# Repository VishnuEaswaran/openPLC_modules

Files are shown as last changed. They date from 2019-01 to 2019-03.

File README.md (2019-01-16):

# OpenPLC Modules

Addon modules for OpenPLC experiments.
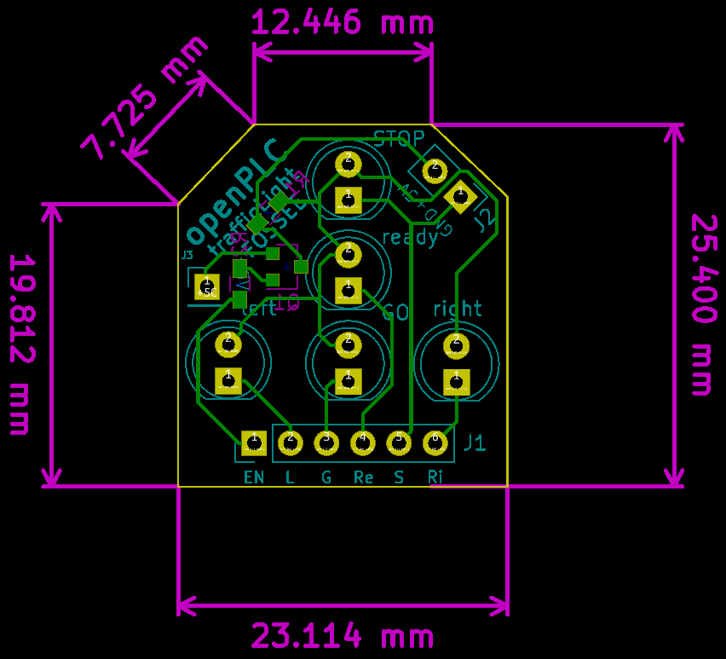
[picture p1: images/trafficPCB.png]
traffic
- Traffic light - represent a 3 way traffic light 
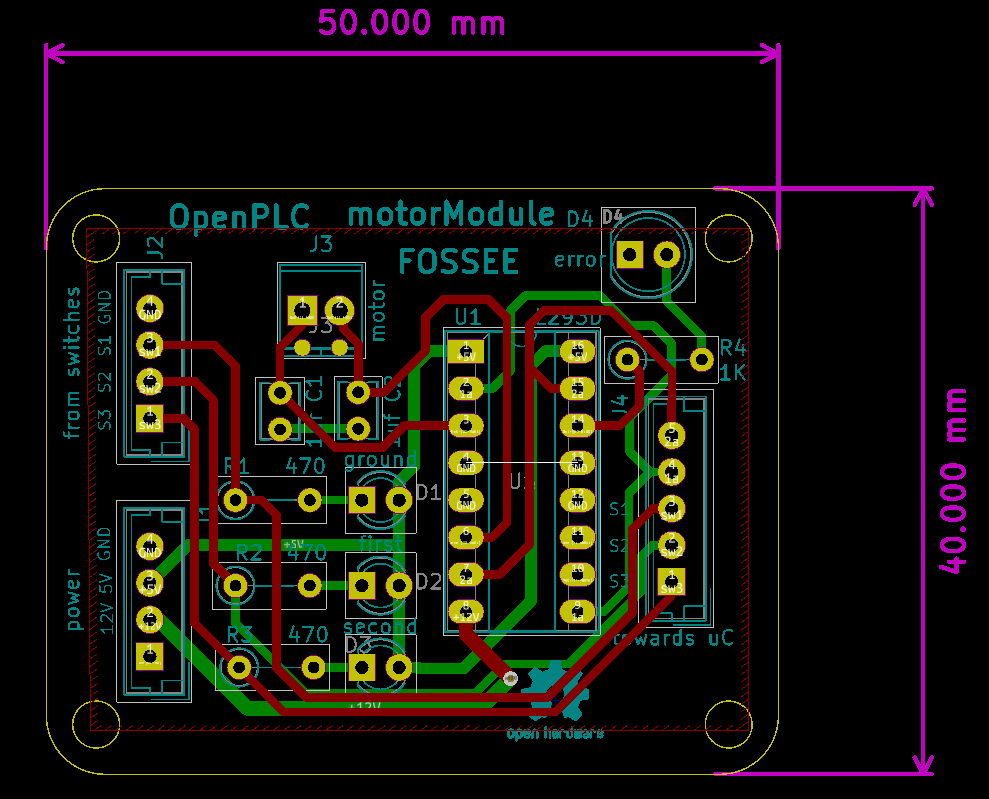
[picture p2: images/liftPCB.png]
- Motor driver for lift - circuit required for driving the motor, receiving and passing on the limit-switch state and as an indicator showing the given logic 
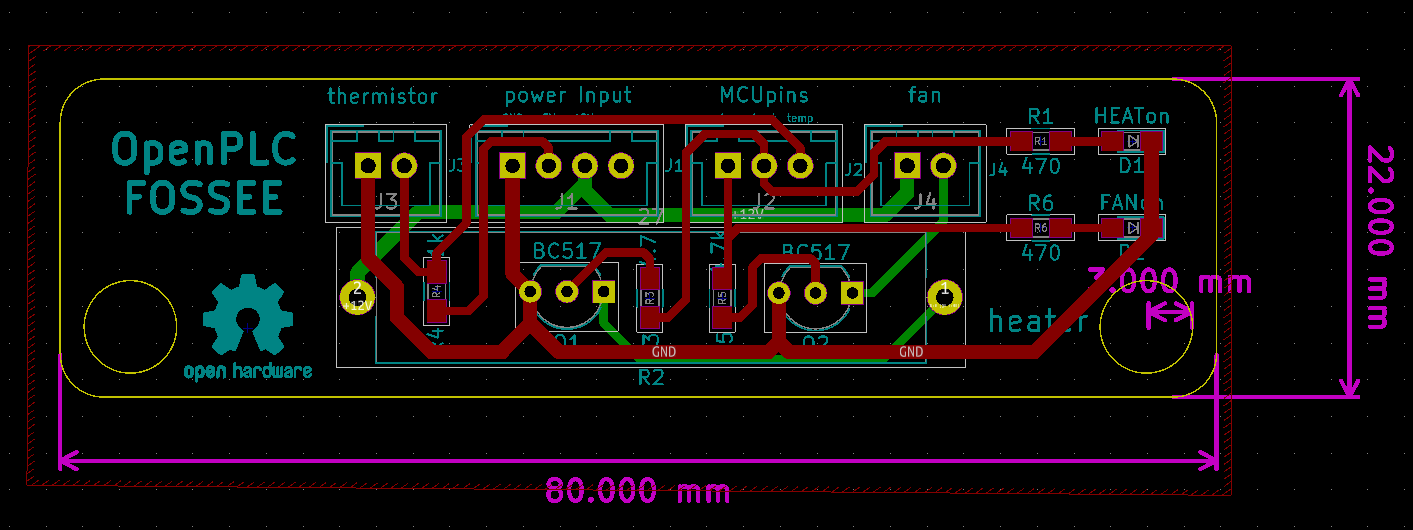
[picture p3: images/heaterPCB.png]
- Heater/temperature control - elements to drive the roister, which also doubles as the heating element, the cooling fan and collecting and passing on thermistor values 
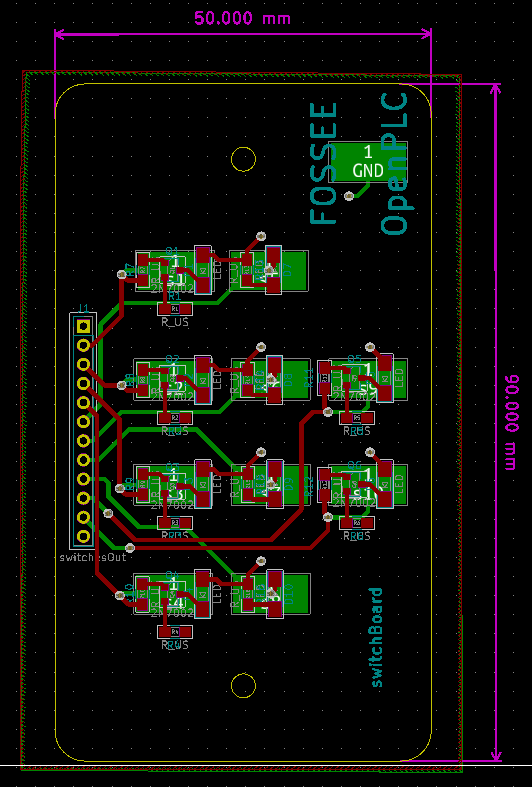
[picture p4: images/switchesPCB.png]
- Switches - an array of a combination of NO, NC and latch switches with indicator LEDs

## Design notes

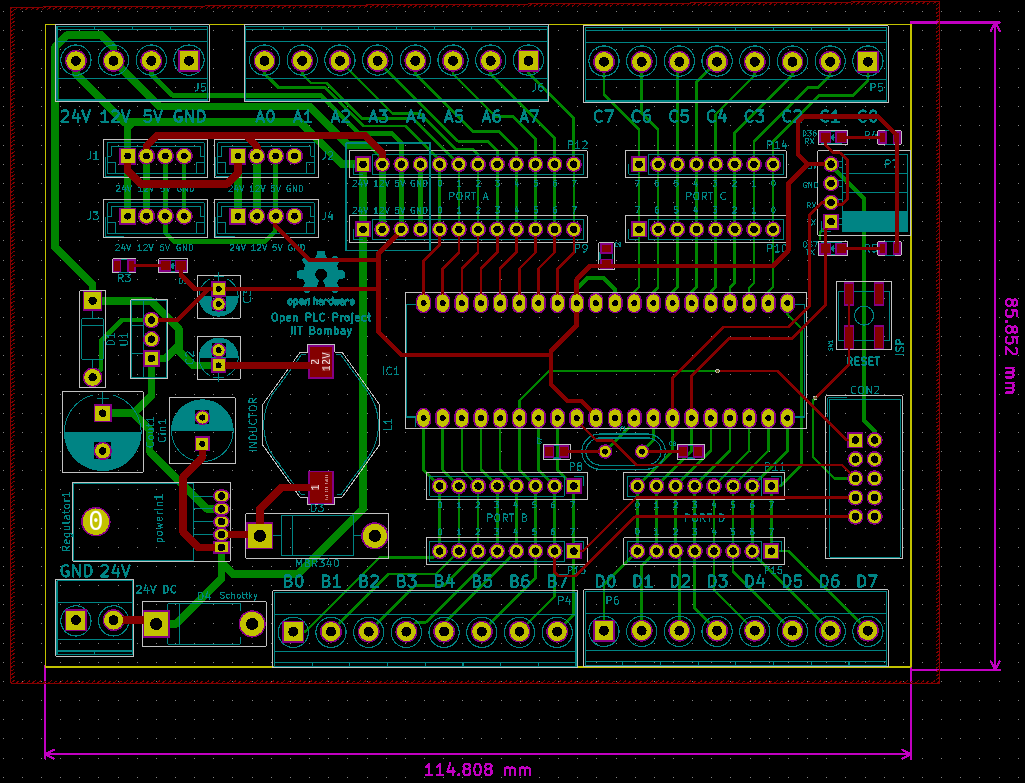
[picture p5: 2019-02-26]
images/v1.png

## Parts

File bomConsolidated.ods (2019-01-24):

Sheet: v1
Date: | Tue 22 Jan 2019 12:48:19 PM IST
Tool: | Eeschema 5.0.1
Component Count: | 41
Individual Components:
Item | Qty | Reference(s) | Value | LibPart | Footprint | Datasheet
 |  | C2 | 100uF | OpenPLC_V2-rescue:CP | Capacitors_THT:CP_Radial_D5.0mm_P2.00mm
 |  | C3 | 10uF | OpenPLC_V2-rescue:CP | Capacitors_THT:CP_Radial_D5.0mm_P2.00mm
 |  | C7 | 22pF | OpenPLC_V2-rescue:CP1 | Capacitors_SMD:C_0805
 |  | C8 | 22pF | OpenPLC_V2-rescue:CP1 | Capacitors_SMD:C_0805
 |  | C9 | 100nF | OpenPLC_V2-rescue:C_Small | Capacitors_SMD:C_0805
 |  | CON2 | AVR-ISP-10 | OpenPLC_V2-rescue:AVR-ISP-10 | IDC:IDC-Header_2x05_Pitch2.54mm_Straight
 |  | Cin1 | 100uf | Device:CP | Capacitors_THT:CP_Radial_D8.0mm_P3.50mm
 |  | Cout1 | 1000uf | Device:CP | Capacitors_THT:CP_Radial_D10.0mm_P5.00mm
 |  | D1 | D | OpenPLC_V2-rescue:D | Diodes_THT:D_DO-41_SOD81_P10.16mm_Horizontal
 |  | D2 | LED | OpenPLC_Kicad_Single_Strip_Unordered-rescue:LED-RESCUE-OpenPLC_Kicad_Single_Strip_Unordered | LEDs:LED_0805
 |  | D3 | MBR340 | Diode:MBR340 | Diodes_THT:D_DO-201AD_P15.24mm_Horizontal | http://www.onsemi.com/pub_link/Collateral/MBR340-D.PDF
 |  | D4 | D_Schottky | OpenPLC_V2-rescue:D_Schottky-Device | Diodes_THT:D_DO-201AD_P12.70mm_Horizontal | ~
 |  | D36 | RX | OpenPLC_Kicad_Single_Strip_Unordered-rescue:LED-RESCUE-OpenPLC_Kicad_Single_Strip_Unordered | LEDs:LED_0805
 |  | D37 | TX | OpenPLC_Kicad_Single_Strip_Unordered-rescue:LED-RESCUE-OpenPLC_Kicad_Single_Strip_Unordered | LEDs:LED_0805
 |  | IC1 | ATMEGA16-P | OpenPLC_Modular-rescue:ATMEGA16-P-RESCUE-OpenPLC_Modular | Housings_DIP:DIP-40_W15.24mm_LongPads
 |  | J1 | Conn_01x04 | OpenPLC_V2-rescue:Conn_01x04 | Connectors_JST:JST_EH_B04B-EH-A_04x2.50mm_Straight
 |  | J2 | Conn_01x04 | OpenPLC_V2-rescue:Conn_01x04 | Connectors_JST:JST_EH_B04B-EH-A_04x2.50mm_Straight
 |  | J3 | Conn_01x04 | OpenPLC_V2-rescue:Conn_01x04 | Connectors_JST:JST_EH_B04B-EH-A_04x2.50mm_Straight
 |  | J4 | Conn_01x04 | OpenPLC_V2-rescue:Conn_01x04 | Connectors_JST:JST_EH_B04B-EH-A_04x2.50mm_Straight
 |  | L1 | INDUCTOR | OpenPLC_V2-rescue:INDUCTOR | Inductors_SMD:L_Fastron_PISR_Handsoldering
 |  | P3 | PortA | OpenPLC_V2-rescue:Conn_01x12 | TerminalBlocks_Phoenix:TerminalBlock_Phoenix_MKDS1.5-12pol
 |  | P4 | PortB | OpenPLC_V2-rescue:Conn_01x08 | TerminalBlocks_Phoenix:TerminalBlock_Phoenix_MKDS1.5-8pol
 |  | P5 | PortC | OpenPLC_V2-rescue:Conn_01x08 | TerminalBlocks_Phoenix:TerminalBlock_Phoenix_MKDS1.5-8pol
 |  | P6 | PortD | OpenPLC_V2-rescue:Conn_01x08 | TerminalBlocks_Phoenix:TerminalBlock_Phoenix_MKDS1.5-8pol
 |  | P7 | Max232 | OpenPLC_V2-rescue:Conn_01x04 | Socket_Strips:Socket_Strip_Angled_1x04_Pitch2.54mm
 |  | P8 | PortB_B | OpenPLC_V2-rescue:Conn_01x08 | Socket_Strips:Socket_Strip_Straight_1x08_Pitch2.54mm
 |  | P9 | PortA_B | OpenPLC_V2-rescue:Conn_01x12 | Socket_Strips:Socket_Strip_Straight_1x12_Pitch2.54mm
 |  | P10 | PortC_B | OpenPLC_V2-rescue:Conn_01x08 | Socket_Strips:Socket_Strip_Straight_1x08_Pitch2.54mm
 |  | P11 | PortD_B | OpenPLC_V2-rescue:Conn_01x08 | Socket_Strips:Socket_Strip_Straight_1x08_Pitch2.54mm
 |  | P12 | PortA_M | OpenPLC_V2-rescue:Conn_01x12 | Pin_Headers:Pin_Header_Straight_1x12_Pitch2.54mm
 |  | P13 | PortB_M | OpenPLC_V2-rescue:Conn_01x08 | Pin_Headers:Pin_Header_Straight_1x08_Pitch2.54mm
 |  | P14 | PortC_M | OpenPLC_V2-rescue:Conn_01x08 | Pin_Headers:Pin_Header_Straight_1x08_Pitch2.54mm
 |  | P15 | PortD_M | OpenPLC_V2-rescue:Conn_01x08 | Pin_Headers:Pin_Header_Straight_1x08_Pitch2.54mm
 |  | R3 | 470E | OpenPLC_V2-rescue:R | Resistors_SMD:R_0805
 |  | R4 | 1K | OpenPLC_V2-rescue:R_Small | Resistors_SMD:R_0805
 |  | R5 | 1K | OpenPLC_V2-rescue:R_Small | Resistors_SMD:R_0805
 |  | Regulator1 | 24 to 12 | Regulator_Switching:LM2576HVT-12 | TO_SOT_Packages_THT:TO-220-5_Horizontal | http://www.ti.com/lit/ds/symlink/lm2576.pdf
 |  | SW1 | SW_PUSH | OpenPLC_V2-rescue:SW_PUSH | Buttons_Switches_SMD:SW_SPST_B3SL-1002P
 |  | U1 | 7805 | OpenPLC_Kicad_Single_Strip_Unordered-rescue:7805-RESCUE-OpenPLC_Kicad_Single_Strip_Unordered | TO_SOT_Packages_THT:TO-220-3_Vertical
 |  | Y1 | 16Mhz | OpenPLC_V2-rescue:Crystal | Crystals:Crystal_HC49-U_Vertical
 |  | powerIn1 | 24V | OpenPLC_V2-rescue:Screw_Terminal_01x02-Connector | TerminalBlocks_Phoenix:TerminalBlock_Phoenix_MKDS1.5-2pol | ~
Collated Components:
Item | Qty | Reference(s) | Value | LibPart | Footprint | Datasheet
1 | 1 | C2 | 100uF | OpenPLC_V2-rescue:CP | Capacitors_THT:CP_Radial_D5.0mm_P2.00mm
2 | 1 | C3 | 10uF | OpenPLC_V2-rescue:CP | Capacitors_THT:CP_Radial_D5.0mm_P2.00mm
3 | 2 | C7, C8 | 22pF | OpenPLC_V2-rescue:CP1 | Capacitors_SMD:C_0805
4 | 1 | C9 | 100nF | OpenPLC_V2-rescue:C_Small | Capacitors_SMD:C_0805
5 | 1 | CON2 | AVR-ISP-10 | OpenPLC_V2-rescue:AVR-ISP-10 | IDC:IDC-Header_2x05_Pitch2.54mm_Straight
6 | 1 | Cin1 | 100uf | Device:CP | Capacitors_THT:CP_Radial_D8.0mm_P3.50mm
7 | 1 | Cout1 | 1000uf | Device:CP | Capacitors_THT:CP_Radial_D10.0mm_P5.00mm
8 | 1 | D1 | D | OpenPLC_V2-rescue:D | Diodes_THT:D_DO-41_SOD81_P10.16mm_Horizontal
9 | 1 | D2 | LED | OpenPLC_Kicad_Single_Strip_Unordered-rescue:LED-RESCUE-OpenPLC_Kicad_Single_Strip_Unordered | LEDs:LED_0805
10 | 1 | D3 | MBR340 | Diode:MBR340 | Diodes_THT:D_DO-201AD_P15.24mm_Horizontal | http://www.onsemi.com/pub_link/Collateral/MBR340-D.PDF
11 | 1 | D4 | D_Schottky | OpenPLC_V2-rescue:D_Schottky-Device | Diodes_THT:D_DO-201AD_P12.70mm_Horizontal | ~
12 | 1 | D36 | RX | OpenPLC_Kicad_Single_Strip_Unordered-rescue:LED-RESCUE-OpenPLC_Kicad_Single_Strip_Unordered | LEDs:LED_0805
13 | 1 | D37 | TX | OpenPLC_Kicad_Single_Strip_Unordered-rescue:LED-RESCUE-OpenPLC_Kicad_Single_Strip_Unordered | LEDs:LED_0805
14 | 1 | IC1 | ATMEGA16-P | OpenPLC_Modular-rescue:ATMEGA16-P-RESCUE-OpenPLC_Modular | Housings_DIP:DIP-40_W15.24mm_LongPads
15 | 4 | J1, J2, J3, J4 | Conn_01x04 | OpenPLC_V2-rescue:Conn_01x04 | Connectors_JST:JST_EH_B04B-EH-A_04x2.50mm_Straight
16 | 1 | L1 | INDUCTOR | OpenPLC_V2-rescue:INDUCTOR | Inductors_SMD:L_Fastron_PISR_Handsoldering
17 | 1 | P3 | PortA | OpenPLC_V2-rescue:Conn_01x12 | TerminalBlocks_Phoenix:TerminalBlock_Phoenix_MKDS1.5-12pol
18 | 1 | P4 | PortB | OpenPLC_V2-rescue:Conn_01x08 | TerminalBlocks_Phoenix:TerminalBlock_Phoenix_MKDS1.5-8pol
19 | 1 | P5 | PortC | OpenPLC_V2-rescue:Conn_01x08 | TerminalBlocks_Phoenix:TerminalBlock_Phoenix_MKDS1.5-8pol
20 | 1 | P6 | PortD | OpenPLC_V2-rescue:Conn_01x08 | TerminalBlocks_Phoenix:TerminalBlock_Phoenix_MKDS1.5-8pol
21 | 1 | P7 | Max232 | OpenPLC_V2-rescue:Conn_01x04 | Socket_Strips:Socket_Strip_Angled_1x04_Pitch2.54mm
22 | 1 | P8 | PortB_B | OpenPLC_V2-rescue:Conn_01x08 | Socket_Strips:Socket_Strip_Straight_1x08_Pitch2.54mm
23 | 1 | P9 | PortA_B | OpenPLC_V2-rescue:Conn_01x12 | Socket_Strips:Socket_Strip_Straight_1x12_Pitch2.54mm
24 | 1 | P10 | PortC_B | OpenPLC_V2-rescue:Conn_01x08 | Socket_Strips:Socket_Strip_Straight_1x08_Pitch2.54mm
25 | 1 | P11 | PortD_B | OpenPLC_V2-rescue:Conn_01x08 | Socket_Strips:Socket_Strip_Straight_1x08_Pitch2.54mm
26 | 1 | P12 | PortA_M | OpenPLC_V2-rescue:Conn_01x12 | Pin_Headers:Pin_Header_Straight_1x12_Pitch2.54mm
27 | 1 | P13 | PortB_M | OpenPLC_V2-rescue:Conn_01x08 | Pin_Headers:Pin_Header_Straight_1x08_Pitch2.54mm
28 | 1 | P14 | PortC_M | OpenPLC_V2-rescue:Conn_01x08 | Pin_Headers:Pin_Header_Straight_1x08_Pitch2.54mm
29 | 1 | P15 | PortD_M | OpenPLC_V2-rescue:Conn_01x08 | Pin_Headers:Pin_Header_Straight_1x08_Pitch2.54mm
30 | 1 | R3 | 470E | OpenPLC_V2-rescue:R | Resistors_SMD:R_0805
31 | 2 | R4, R5 | 1K | OpenPLC_V2-rescue:R_Small | Resistors_SMD:R_0805
32 | 1 | Regulator1 | 24 to 12 | Regulator_Switching:LM2576HVT-12 | TO_SOT_Packages_THT:TO-220-5_Horizontal | http://www.ti.com/lit/ds/symlink/lm2576.pdf
33 | 1 | SW1 | SW_PUSH | OpenPLC_V2-rescue:SW_PUSH | Buttons_Switches_SMD:SW_SPST_B3SL-1002P
34 | 1 | U1 | 7805 | OpenPLC_Kicad_Single_Strip_Unordered-rescue:7805-RESCUE-OpenPLC_Kicad_Single_Strip_Unordered | TO_SOT_Packages_THT:TO-220-3_Vertical
35 | 1 | Y1 | 16Mhz | OpenPLC_V2-rescue:Crystal | Crystals:Crystal_HC49-U_Vertical
36 | 1 | powerIn1 | 24V | OpenPLC_V2-rescue:Screw_Terminal_01x02-Connector | TerminalBlocks_Phoenix:TerminalBlock_Phoenix_MKDS1.5-2pol | ~
Extras
Item | Qty | Part
1 | 1 | USB-ASP Programmer
2 | 1 | Programmer cable

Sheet: traffic
Date: | Tue 22 Jan 2019 05:36:43 PM IST
Tool: | Eeschema 5.0.1
Component Count: | 11
Individual Components:
Reference(s) | Value | LibPart | Footprint | Datasheet
D1 | left | Device:LED | LEDs:LED_D5.0mm | ~
D2 | GO | Device:LED | LEDs:LED_D5.0mm | ~
D3 | right | Device:LED | LEDs:LED_D5.0mm | ~
D4 | ready | Device:LED | LEDs:LED_D5.0mm | ~
D5 | STOP | Device:LED | LEDs:LED_D5.0mm | ~
J1 | Conn_01x06_Male | Connector:Conn_01x06_Male | Socket_Strips:Socket_Strip_Straight_1x06_Pitch2.54mm | ~
J2 | Conn_01x02_Male | Connector:Conn_01x02_Male | Socket_Strips:Socket_Strip_Straight_1x02_Pitch2.54mm | ~
J3 | Conn_01x01_Male | Connector:Conn_01x01_Male | Socket_Strips:Socket_Strip_Straight_1x01_Pitch2.54mm |  |  | ~
Q1 | MMBT3906 | Transistor_BJT:MMBT3906 | TO_SOT_Packages_SMD:SOT-23 | https://www.fairchildsemi.com/datasheets/2N/2N3906.pdf | Q1 | MMBT3906 | Transistor_BJT:MMBT3906 | TO_SOT_Packages_SMD:SOT-23 | https://www.fairchildsemi.com/datasheets/2N/2N3906.pdf | Q1 | MMBT3906 | Transistor_BJT:MMBT3906 | TO_SOT_Packages_SMD:SOT-23 | https://www.fairchildsemi.com/datasheets/2N/2N3906.pdf | Q1 | MMBT3906 | Transistor_BJT:MMBT3906 | TO_SOT_Packages_SMD:SOT-23 | https://www.fairchildsemi.com/datasheets/2N/2N3906.pdf | Q1 | MMBT3906 | Transistor_BJT:MMBT3906 | TO_SOT_Packages_SMD:SOT-23 | https://www.fairchildsemi.com/datasheets/2N/2N3906.pdf | Q1 | MMBT3906 | Transistor_BJT:MMBT3906 | TO_SOT_Packages_SMD:SOT-23 | https://www.fairchildsemi.com/datasheets/2N/2N3906.pdf | Q1 | MMBT3906 | Transistor_BJT:MMBT3906 | TO_SOT_Packages_SMD:SOT-23 | https://www.fairchildsemi.com/datasheets/2N/2N3906.pdf | Q1 | MMBT3906 | Transistor_BJT:MMBT3906 | TO_SOT_Packages_SMD:SOT-23 | https://www.fairchildsemi.com/datasheets/2N/2N3906.pdf | Q1 | MMBT3906 | Transistor_BJT:MMBT3906 | TO_SOT_Packages_SMD:SOT-23 | https://www.fairchildsemi.com/datasheets/2N/2N3906.pdf | Q1 | MMBT3906 | Transistor_BJT:MMBT3906 | TO_SOT_Packages_SMD:SOT-23 | https://www.fairchildsemi.com/datasheets/2N/2N3906.pdf | Q1 | MMBT3906 | Transistor_BJT:MMBT3906 | TO_SOT_Packages_SMD:SOT-23 | https://www.fairchildsemi.com/datasheets/2N/2N3906.pdf | Q1 | MMBT3906 | Transistor_BJT:MMBT3906 | TO_SOT_Packages_SMD:SOT-23 | https://www.fairchildsemi.com/datasheets/2N/2N3906.pdf
R1 | R | Device:R | Resistors_SMD:R_0603_HandSoldering | ~
R2 | R | Device:R | Resistors_SMD:R_0603_HandSoldering | ~
Collated Components:
Item | Qty | Reference(s) | Value | LibPart | Footprint | Datasheet
1 | 1 | D1 | left | Device:LED – green | LEDs:LED_D5.0mm | ~
2 | 1 | D2 | GO | Device:LED – green | LEDs:LED_D5.0mm | ~
3 | 1 | D3 | right | Device:LED – green | LEDs:LED_D5.0mm | ~
4 | 1 | D4 | ready | Device:LED – orange | LEDs:LED_D5.0mm | ~
5 | 1 | D5 | STOP | Device:LED – green | LEDs:LED_D5.0mm | ~
6 | 1 | J1 | Conn_01x06_Male | Connector:Conn_01x06_Male | Socket_Strips:Socket_Strip_Straight_1x06_Pitch2.54mm | ~
7 | 1 | J2 | Conn_01x02_Male | Connector:Conn_01x02_Male | Socket_Strips:Socket_Strip_Straight_1x02_Pitch2.54mm | ~
8 | 1 | J3 | Conn_01x01_Male | Connector:Conn_01x01_Male | Socket_Strips:Socket_Strip_Straight_1x01_Pitch2.54mm | ~
9 | 1 | Q1 | MMBT3906 | Transistor_BJT:MMBT3906 | TO_SOT_Packages_SMD:SOT-23 | https://www.fairchildsemi.com/datasheets/2N/2N3906.pdf
10 | 2 | R1, R2 | R | Device:R | Resistors_SMD:R_0603_HandSoldering | ~

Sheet: motor
Date: | Tue 22 Jan 2019 12:15:49 PM IST
Tool: | Eeschema 5.0.1
Component Count: | 15
Individual Components:
Reference(s) | Value | LibPart | Footprint | Datasheet
C1 | 1uf | Device:C | Capacitors_THT:C_Disc_D3.8mm_W2.6mm_P2.50mm | ~
C2 | 1uf | Device:C | Capacitors_THT:C_Disc_D3.8mm_W2.6mm_P2.50mm | ~
D1 | LED | Device:LED | LEDs:LED_D3.0mm | ~
D2 | LED | Device:LED | LEDs:LED_D3.0mm | ~
D3 | LED | Device:LED | LEDs:LED_D3.0mm | ~
D4 | error | Device:LED | LEDs:LED_D5.0mm | ~
J1 | power | Connector:Conn_01x04_Male | Connectors_JST:JST_EH_B04B-EH-A_04x2.50mm_Straight | ~
J2 | from switches | Connector:Conn_01x04_Male | Connectors_JST:JST_EH_B04B-EH-A_04x2.50mm_Straight | ~
J3 | motor | Connector:Screw_Terminal_01x02 | TerminalBlocks_Phoenix:TerminalBlock_Phoenix_MPT-2.54mm_2pol | ~
J4 | towards uC | Connector:Conn_01x05_Male | Connectors_JST:JST_EH_B05B-EH-A_05x2.50mm_Straight | ~
R1 | 470 | Device:R_US | Resistors_THT:R_Axial_DIN0207_L6.3mm_D2.5mm_P5.08mm_Vertical | ~
R2 | 470 | Device:R_US | Resistors_THT:R_Axial_DIN0207_L6.3mm_D2.5mm_P5.08mm_Vertical | ~
R3 | 470 | Device:R_US | Resistors_THT:R_Axial_DIN0207_L6.3mm_D2.5mm_P5.08mm_Vertical | ~
R4 | 1K | Device:R_US | Resistors_THT:R_Axial_DIN0207_L6.3mm_D2.5mm_P5.08mm_Vertical | ~
U1 | L293D | Driver_Motor:L293D | Housings_DIP:DIP-16_W7.62mm_Socket_LongPads | http://www.ti.com/lit/ds/symlink/l293.pdf
Collated Components:
Item | Qty | Reference(s) | Value | LibPart | Footprint | Datasheet
1 | 2 | C1, C2 | 1uf | Device:C | Capacitors_THT:C_Disc_D3.8mm_W2.6mm_P2.50mm | ~
2 | 3 | D1, D2, D3 | LED | Device:LED – green | LEDs:LED_D3.0mm | ~
3 | 1 | D4 | error | Device:LED – red | LEDs:LED_D5.0mm | ~
4 | 1 | J1 | power | Connector:Conn_01x04_Male | Connectors_JST:JST_EH_B04B-EH-A_04x2.50mm_Straight | ~
5 | 1 | J2 | from switches | Connector:Conn_01x04_Male | Connectors_JST:JST_EH_B04B-EH-A_04x2.50mm_Straight | ~
6 | 1 | J3 | motor | Connector:Screw_Terminal_01x02 | TerminalBlocks_Phoenix:TerminalBlock_Phoenix_MPT-2.54mm_2pol | ~
7 | 1 | J4 | towards uC | Connector:Conn_01x05_Male | Connectors_JST:JST_EH_B05B-EH-A_05x2.50mm_Straight | ~
8 | 3 | R1, R2, R3 | 470 | Device:R_US | Resistors_THT:R_Axial_DIN0207_L6.3mm_D2.5mm_P5.08mm_Vertical | ~
9 | 1 | R4 | 1K | Device:R_US | Resistors_THT:R_Axial_DIN0207_L6.3mm_D2.5mm_P5.08mm_Vertical | ~
10 | 1 | U1 | L293D | Driver_Motor:L293D | Housings_DIP:DIP-16_W7.62mm_Socket_LongPads | http://www.ti.com/lit/ds/symlink/l293.pdf

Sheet: heater
Date: | Tue 22 Jan 2019 12:19:13 PM IST
Tool: | Eeschema 5.0.1
Component Count: | 14
Date Issue | 2019-01-04
Individual Components:
Reference(s) | Value | LibPart | Footprint | Datasheet
D1 | LED | Device:LED | LEDs:LED_0805_HandSoldering | ~
D2 | LED | Device:LED | LEDs:LED_0805_HandSoldering | ~
J1 | power Input | Connector:Conn_01x04_Female | Connectors_JST:JST_XH_B04B-XH-A_04x2.50mm_Straight | ~
J2 | MCUpins | Connector:Conn_01x03_Male | Connectors_JST:JST_XH_B03B-XH-A_03x2.50mm_Straight | ~
J3 | thermistor | Connector:Conn_01x02_Male | Connectors_JST:JST_XH_B02B-XH-A_02x2.50mm_Straight | ~
J4 | fan | Connector:Conn_01x02_Male | Connectors_JST:JST_XH_B02B-XH-A_02x2.50mm_Straight | ~
Q1 | BC517 | Transistor_BJT:BC517 | TO_SOT_Packages_THT:TO-92_Inline_Wide | http://www.fairchildsemi.com/ds/BC/BC517.pdf
Q2 | BC517 | Transistor_BJT:BC517 | TO_SOT_Packages_THT:TO-92_Inline_Wide | http://www.fairchildsemi.com/ds/BC/BC517.pdf
R1 | 470 | Device:R_US | Resistors_SMD:R_0805_HandSoldering | ~
R2 | 27 | Device:R_US | Resistors_THT:R_Axial_Power_L38.0mm_W9.0mm_P40.64mm | ~
R3 | 4.7 | Device:R_US | Resistors_SMD:R_0805_HandSoldering | ~
R4 | 1k | Device:R_US | Resistors_SMD:R_0805_HandSoldering | ~
R5 | 4.7k | Device:R_US | Resistors_SMD:R_0805_HandSoldering | ~
R6 | 470 | Device:R_US | Resistors_SMD:R_0805_HandSoldering | ~
Collated Components:
Item | Qty | Reference(s) | Value | LibPart | Footprint | Datasheet
1 | 2 | D1, D2 | LED | Device:LED | LEDs:LED_0805_HandSoldering | ~
2 | 1 | J1 | power Input | Connector:Conn_01x04_Female | Connectors_JST:JST_XH_B04B-XH-A_04x2.50mm_Straight | ~
3 | 1 | J2 | MCUpins | Connector:Conn_01x03_Male | Connectors_JST:JST_XH_B03B-XH-A_03x2.50mm_Straight | ~
4 | 1 | J3 | thermistor | Connector:Conn_01x02_Male | Connectors_JST:JST_XH_B02B-XH-A_02x2.50mm_Straight | ~
5 | 1 | J4 | fan | Connector:Conn_01x02_Male | Connectors_JST:JST_XH_B02B-XH-A_02x2.50mm_Straight | ~
6 | 2 | Q1, Q2 | BC517 | Transistor_BJT:BC517 | TO_SOT_Packages_THT:TO-92_Inline_Wide | http://www.fairchildsemi.com/ds/BC/BC517.pdf
7 | 2 | R1, R6 | 470 | Device:R_US | Resistors_SMD:R_0805_HandSoldering | ~
8 | 1 | R2 | 27 | Device:R_US | Resistors_THT:R_Axial_Power_L38.0mm_W9.0mm_P40.64mm | ~
9 | 1 | R3 | 4.7 | Device:R_US | Resistors_SMD:R_0805_HandSoldering | ~
10 | 1 | R4 | 1k | Device:R_US | Resistors_SMD:R_0805_HandSoldering | ~
11 | 1 | R5 | 4.7k | Device:R_US | Resistors_SMD:R_0805_HandSoldering | ~

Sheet: switches
Date: | Tue 22 Jan 2019 11:39:28 AM IST
Tool: | Eeschema 5.0.1
Component Count: | 44
Individual Components:
Reference(s) | Value | LibPart | Footprint | Datasheet
D1 | LED | Device:LED | LEDs:LED_1206_HandSoldering | ~
D2 | LED | Device:LED | LEDs:LED_1206_HandSoldering | ~
D3 | LED | Device:LED | LEDs:LED_1206_HandSoldering | ~
D4 | LED | Device:LED | LEDs:LED_1206_HandSoldering | ~
D5 | LED | Device:LED | LEDs:LED_1206_HandSoldering | ~
D6 | LED | Device:LED | LEDs:LED_1206_HandSoldering | ~
D7 | LED | Device:LED | LEDs:LED_1206_HandSoldering | ~
D8 | LED | Device:LED | LEDs:LED_1206_HandSoldering | ~
D9 | LED | Device:LED | LEDs:LED_1206_HandSoldering | ~
D10 | LED | Device:LED | LEDs:LED_1206_HandSoldering | ~
J1 | switchesOut | Connector:Conn_01x12_Male | Socket_Strips:Socket_Strip_Straight_1x12_Pitch2.54mm | ~
J2 | Conn_01x01_Female | Connector:Conn_01x01_Female | Wire_Pads:SolderWirePad_single_SMD_5x10mm | ~
J3 | Conn_01x01_Female | Connector:Conn_01x01_Female | Wire_Pads:SolderWirePad_single_SMD_5x10mm | ~
J4 | Conn_01x01_Female | Connector:Conn_01x01_Female | Wire_Pads:SolderWirePad_single_SMD_5x10mm | ~
J5 | Conn_01x01_Female | Connector:Conn_01x01_Female | Wire_Pads:SolderWirePad_single_SMD_5x10mm | ~
J6 | Conn_01x01_Female | Connector:Conn_01x01_Female | Wire_Pads:SolderWirePad_single_SMD_5x10mm | ~
J7 | Conn_01x01_Female | Connector:Conn_01x01_Female | Wire_Pads:SolderWirePad_single_SMD_5x10mm | ~
J8 | Conn_01x01_Female | Connector:Conn_01x01_Female | Wire_Pads:SolderWirePad_single_SMD_5x10mm | ~
J9 | Conn_01x01_Female | Connector:Conn_01x01_Female | Wire_Pads:SolderWirePad_single_SMD_5x10mm | ~
J10 | Conn_01x01_Female | Connector:Conn_01x01_Female | Wire_Pads:SolderWirePad_single_SMD_5x10mm | ~
J11 | Conn_01x01_Female | Connector:Conn_01x01_Female | Wire_Pads:SolderWirePad_single_SMD_5x10mm | ~
J12 | Conn_01x01_Female | Connector:Conn_01x01_Female | Wire_Pads:SolderWirePad_single_SMD_5x10mm | ~
Q1 | 2N7002 | Transistor_FET:2N7002 | TO_SOT_Packages_SMD:SOT-23 | https://www.fairchildsemi.com/datasheets/2N/2N7002.pdf
Q2 | 2N7002 | Transistor_FET:2N7002 | TO_SOT_Packages_SMD:SOT-23 | https://www.fairchildsemi.com/datasheets/2N/2N7002.pdf
Q3 | 2N7002 | Transistor_FET:2N7002 | TO_SOT_Packages_SMD:SOT-23 | https://www.fairchildsemi.com/datasheets/2N/2N7002.pdf
Q4 | 2N7002 | Transistor_FET:2N7002 | TO_SOT_Packages_SMD:SOT-23 | https://www.fairchildsemi.com/datasheets/2N/2N7002.pdf
Q5 | 2N7002 | Transistor_FET:2N7002 | TO_SOT_Packages_SMD:SOT-23 | https://www.fairchildsemi.com/datasheets/2N/2N7002.pdf
Q6 | 2N7002 | Transistor_FET:2N7002 | TO_SOT_Packages_SMD:SOT-23 | https://www.fairchildsemi.com/datasheets/2N/2N7002.pdf
R1 | R_US | Device:R_US | Resistors_SMD:R_0805_HandSoldering | ~
R2 | R_US | Device:R_US | Resistors_SMD:R_0805_HandSoldering | ~
R3 | R_US | Device:R_US | Resistors_SMD:R_0805_HandSoldering | ~
R4 | R_US | Device:R_US | Resistors_SMD:R_0805_HandSoldering | ~
R5 | R_US | Device:R_US | Resistors_SMD:R_0805_HandSoldering | ~
R6 | R_US | Device:R_US | Resistors_SMD:R_0805_HandSoldering | ~
R7 | R_US | Device:R_US | Resistors_SMD:R_0805_HandSoldering | ~
R8 | R_US | Device:R_US | Resistors_SMD:R_0805_HandSoldering | ~
R9 | R_US | Device:R_US | Resistors_SMD:R_0805_HandSoldering | ~
R10 | R_US | Device:R_US | Resistors_SMD:R_0805_HandSoldering | ~
R11 | R_US | Device:R_US | Resistors_SMD:R_0805_HandSoldering | ~
R12 | R_US | Device:R_US | Resistors_SMD:R_0805_HandSoldering | ~
R13 | R_US | Device:R_US | Resistors_SMD:R_0805_HandSoldering | ~
R14 | R_US | Device:R_US | Resistors_SMD:R_0805_HandSoldering | ~
R15 | R_US | Device:R_US | Resistors_SMD:R_0805_HandSoldering | ~
R16 | R_US | Device:R_US | Resistors_SMD:R_0805_HandSoldering | ~
Collated Components:
Item | Qty | Reference(s) | Value | LibPart | Footprint | Datasheet
1 | 10 | D1, D2, D3, D4, D5, D6, D7, D8, D9, D10 | LED | Device:LED | LEDs:LED_1206_HandSoldering | ~
2 | 1 | J1 | switchesOut | Connector:Conn_01x12_Male | Socket_Strips:Socket_Strip_Straight_1x12_Pitch2.54mm | ~
3 | 11 | J2, J3, J4, J5, J6, J7, J8, J9, J10, J11, J12 | Conn_01x01_Female | Connector:Conn_01x01_Female | Wire_Pads:SolderWirePad_single_SMD_5x10mm | ~
4 | 6 | Q1, Q2, Q3, Q4, Q5, Q6 | 2N7002 | Transistor_FET:2N7002 | TO_SOT_Packages_SMD:SOT-23 | https://www.fairchildsemi.com/datasheets/2N/2N7002.pdf
5 | 16 | R1, R2, R3, R4, R5, R6, R7, R8, R9, R10, R11, R12, R13, R14, R15, R16 | R_US | Device:R_US | Resistors_SMD:R_0805_HandSoldering | ~
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

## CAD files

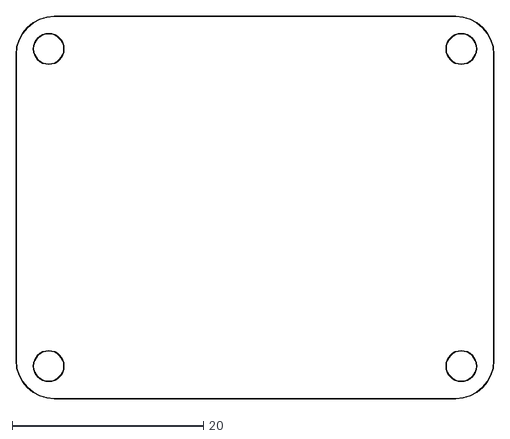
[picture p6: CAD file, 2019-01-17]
motor/motorCutlines.dxf
50.0 x 40.0

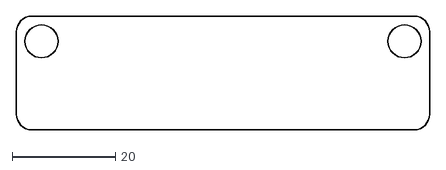
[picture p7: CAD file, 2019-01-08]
heater/heaterBoard.dxf
80.0 x 22.0

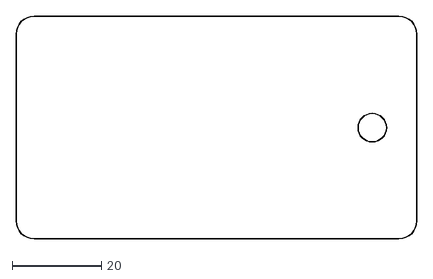
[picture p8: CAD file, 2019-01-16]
switches/cutlineSwitch.dxf
90.0 x 50.0

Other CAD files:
heater/boardOutline.fcstd
switches/boardoutlineSwithes.fcstd
motor/motorPCB.fcstd

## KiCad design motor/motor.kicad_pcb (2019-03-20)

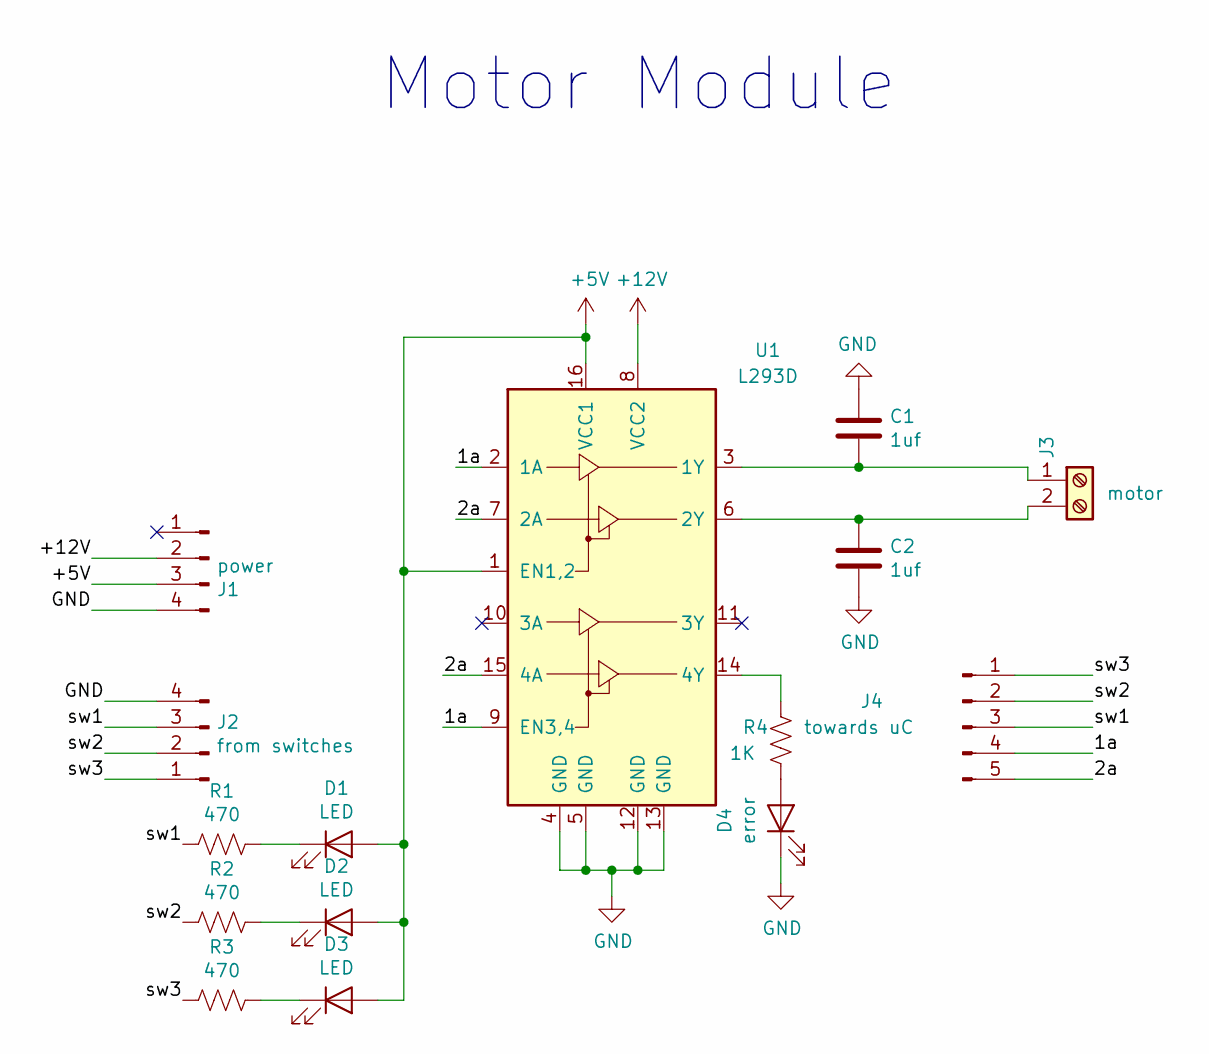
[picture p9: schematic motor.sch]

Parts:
C1, C2: 1uf; C_Disc_D3.8mm_W2.6mm_P2.50mm
D1, D2, D3: LED; LED_D3.0mm
D4: error; LED_D5.0mm
J1: power; JST_EH_B04B-EH-A_04x2.50mm_Straight
J2: from switches; JST_EH_B04B-EH-A_04x2.50mm_Straight
J3: motor; TerminalBlock_Phoenix_MPT-2.54mm_2pol
J4: towards uC; JST_EH_B05B-EH-A_05x2.50mm_Straight
R1, R2, R3: 470; R_Axial_DIN0207_L6.3mm_D2.5mm_P5.08mm_Vertical
R4: 1K; R_Axial_DIN0207_L6.3mm_D2.5mm_P5.08mm_Vertical
U1: L293D; DIP-16_W7.62mm_Socket_LongPads

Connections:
+5V: D1.2 (A), D2.2 (A), D3.2 (A), J1.3, U1.1 (EN1,2), U1.16 (VCC1)
+12V: J1.2, U1.8 (VCC2)
/1a: J4.4, U1.2 (1A), U1.9 (EN3,4)
/2a: J4.5, U1.7 (2A), U1.15 (4A)
/sw1: J2.3, J4.3, R1.1
/sw2: J2.2, J4.2, R2.1
/sw3: J2.1, J4.1, R3.1
GND: C1.1, C2.2, D4.1 (K), J1.4, J2.4, U1.4 (GND), U1.5 (GND), U1.12 (GND), U1.13 (GND)
unnamed: C1.2, J3.1, U1.3 (1Y)
unnamed: C2.1, J3.2, U1.6 (2Y)
unnamed: D1.1 (K), R1.2
unnamed: D2.1 (K), R2.2
unnamed: D3.1 (K), R3.2
unnamed: D4.2 (A), R4.2
unnamed: R4.1, U1.14 (4Y)

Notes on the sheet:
Motor Module

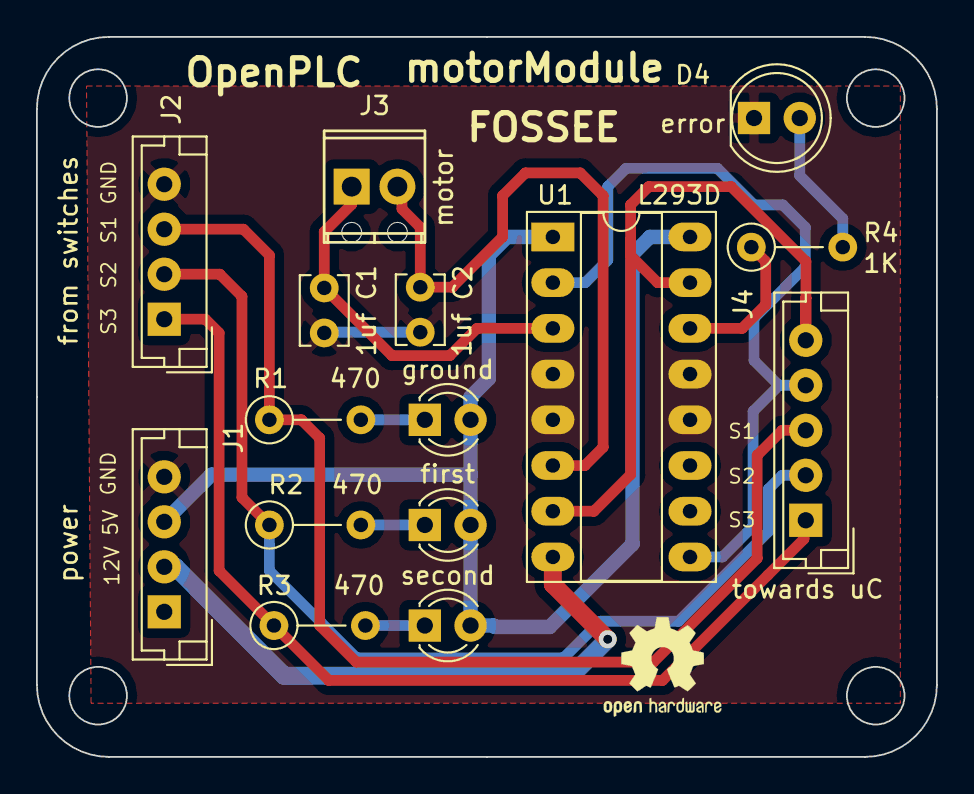
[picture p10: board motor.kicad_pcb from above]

Board: 2 copper layers, 50.0 x 40.0 mm, 15 parts (0 on the bottom side), 15 nets.

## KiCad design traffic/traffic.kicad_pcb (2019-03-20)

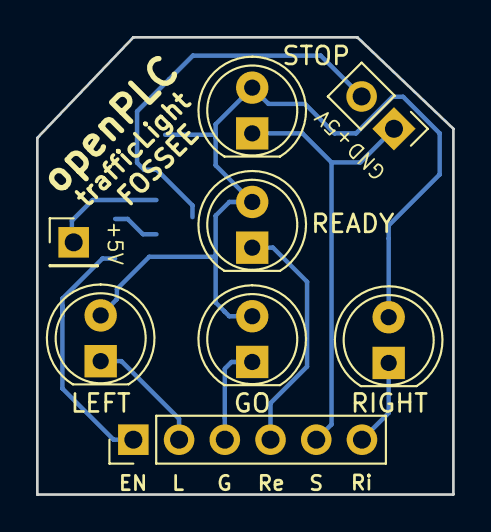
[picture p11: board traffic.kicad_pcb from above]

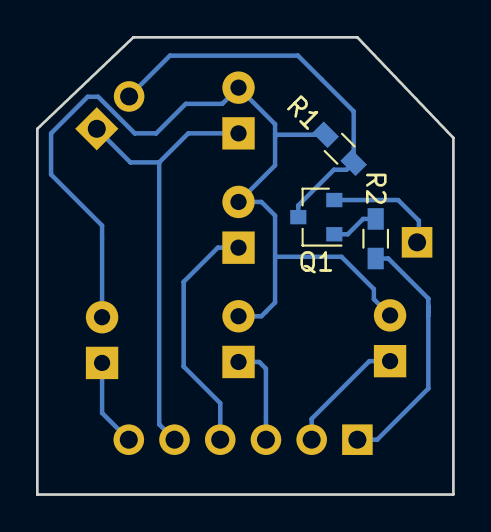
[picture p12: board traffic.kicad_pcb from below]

Board: 2 copper layers, 23.1 x 25.4 mm, 11 parts (3 on the bottom side), 10 nets.

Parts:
D1: LEFT; LED_D5.0mm
D2: GO; LED_D5.0mm
D3: RIGHT; LED_D5.0mm
D4: READY; LED_D5.0mm
D5: STOP; LED_D5.0mm
J1: Conn_01x06_Male; Socket_Strip_Straight_1x06_Pitch2.54mm
J2: Conn_01x02_Male; Socket_Strip_Straight_1x02_Pitch2.54mm
J3: Conn_01x01_Male; Socket_Strip_Straight_1x01_Pitch2.54mm
Q1: MMBT3906; SOT-23
R1, R2: R; R_0603_HandSoldering

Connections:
+5C: J3.1, Q1.2
unnamed: D1.1, J1.2
unnamed: D1.2, D2.2, D3.2, D4.2, D5.2, R1.1
unnamed: D2.1, J1.3
unnamed: D3.1, J1.6
unnamed: D4.1, J1.4
unnamed: D5.1, J1.5, J2.1
unnamed: J1.1, R2.2
unnamed: J2.2, Q1.3, R1.2
unnamed: Q1.1, R2.1

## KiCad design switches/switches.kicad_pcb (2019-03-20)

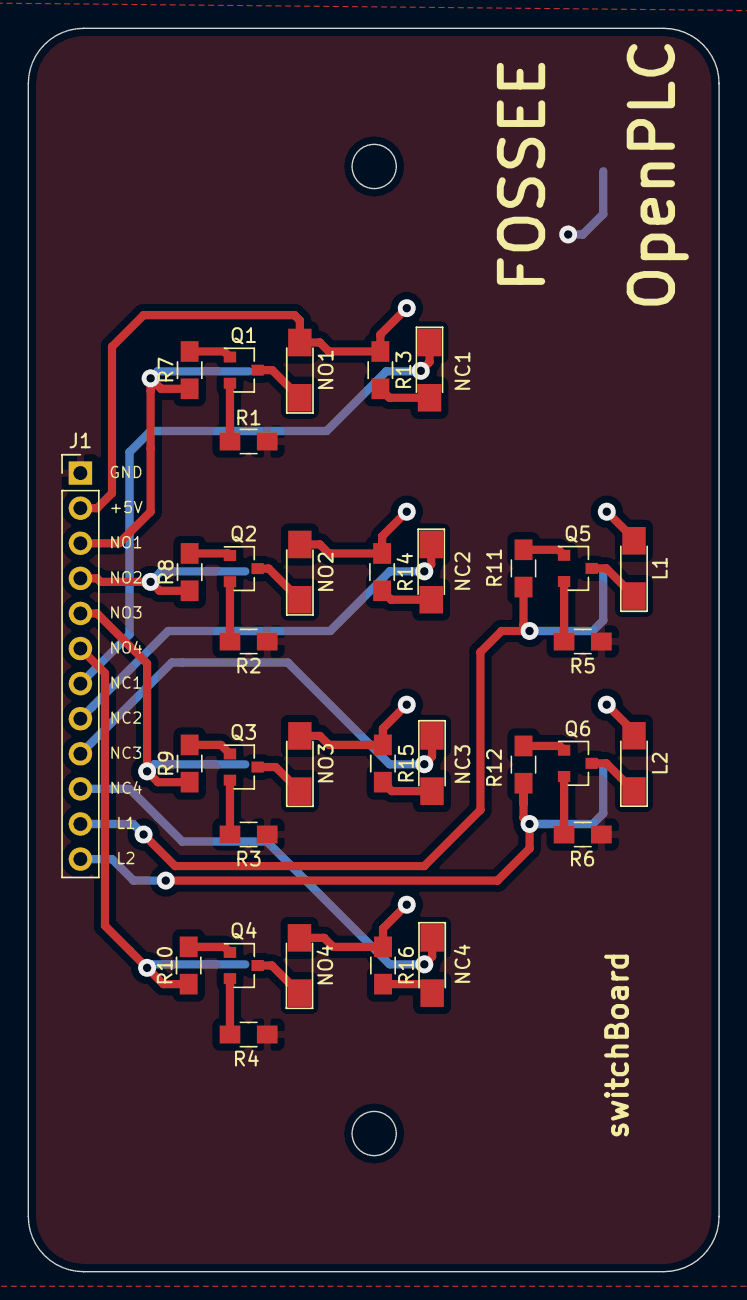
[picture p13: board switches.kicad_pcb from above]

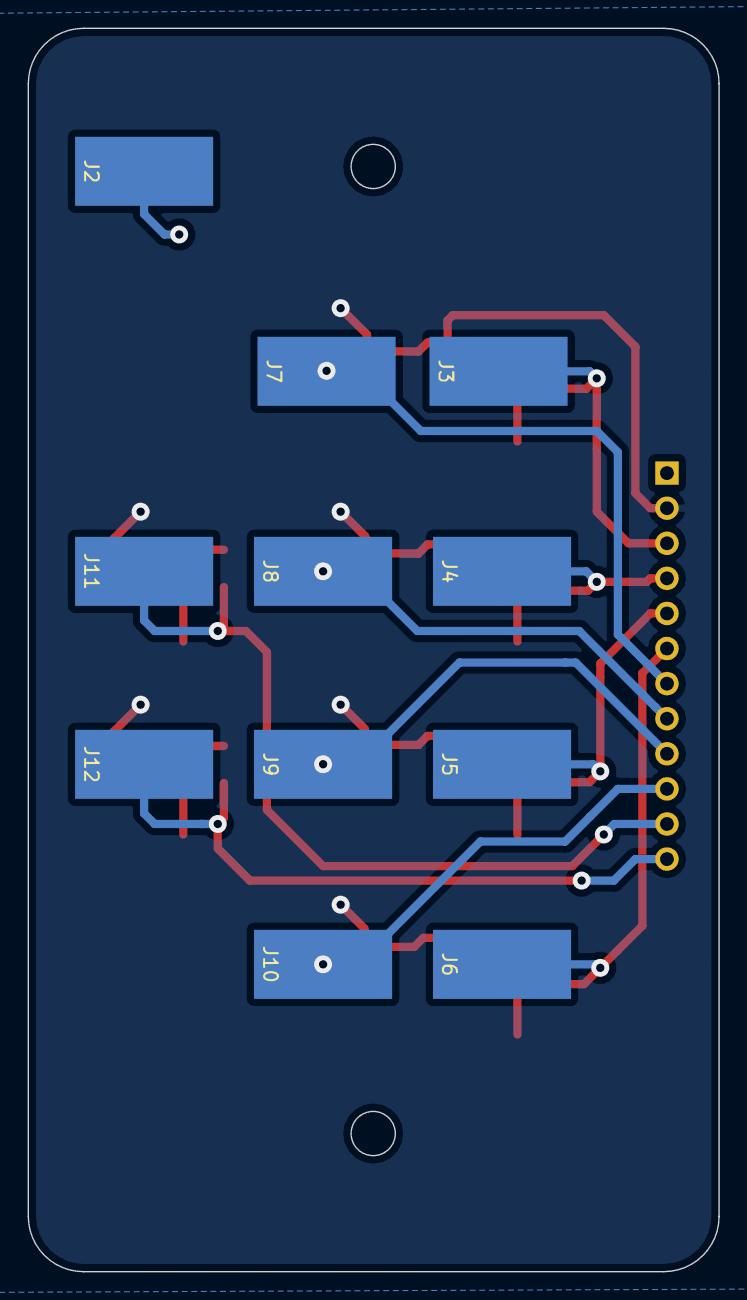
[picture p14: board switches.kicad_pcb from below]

Board: 2 copper layers, 50.0 x 90.0 mm, 44 parts (11 on the bottom side), 34 nets.

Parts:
D1: NO1; LED_1206_HandSoldering
D2: NO2; LED_1206_HandSoldering
D3: NO3; LED_1206_HandSoldering
D4: NO4; LED_1206_HandSoldering
D5: L1; LED_1206_HandSoldering
D6: L2; LED_1206_HandSoldering
D7: NC1; LED_1206_HandSoldering
D8: NC2; LED_1206_HandSoldering
D9: NC3; LED_1206_HandSoldering
D10: NC4; LED_1206_HandSoldering
J1: switchesOut; Socket_Strip_Straight_1x12_Pitch2.54mm
J2, J3, J4, J5, J6, J7, J8, J9, J10, J11, J12: Conn_01x01_Female; SolderWirePad_single_SMD_5x10mm
Q1, Q2, Q3, Q4, Q5, Q6: 2N7002; SOT-23
R1, R2, R3, R4, R5, R6, R7, R8, R9, R10, R11, R12, R13, R14, R15, R16: R_US; R_0805_HandSoldering

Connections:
+5V: D1.2, D2.2, D3.2, D4.2, D5.2, D6.2, J1.2, R13.1, R14.1, R15.1, R16.1
/s1: J1.3, J3.1, R7.1
/s2: J1.4, J4.1, R8.1
/s3: J1.5, J5.1, R9.1
/s4: J1.6, J6.1, R10.1
/s5: D7.1, J1.7, J7.1
/s6: D8.1, J1.8, J8.1
/s7: D9.1, J1.9, J9.1
/s8: D10.1, J1.10, J10.1
/s9: J1.11, J11.1, R11.1
/s10: J1.12, J12.1, R12.1
GND: J1.1, J2.1, R1.2, R2.2, R3.2, R4.2, R5.2, R6.2
unnamed: D1.1, Q1.3
unnamed: D2.1, Q2.3
unnamed: D3.1, Q3.3
unnamed: D4.1, Q4.3
unnamed: D5.1, Q5.3
unnamed: D6.1, Q6.3
unnamed: D7.2, R13.2
unnamed: D8.2, R14.2
unnamed: D9.2, R15.2
unnamed: D10.2, R16.2
unnamed: Q1.1, R7.2
unnamed: Q1.2, R1.1
unnamed: Q2.1, R8.2
unnamed: Q2.2, R2.1
unnamed: Q3.1, R9.2
unnamed: Q3.2, R3.1
unnamed: Q4.1, R10.2
unnamed: Q4.2, R4.1
unnamed: Q5.1, R11.2
unnamed: Q5.2, R5.1
unnamed: Q6.1, R12.2
unnamed: Q6.2, R6.1

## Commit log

2019-01-04 gti initiated and push to github
    [motor.kicad_pcb, motor.sch, openplc_modules.kicad_pcb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]
2019-01-07 changed LEds from 3mm to 5mm;added Status LED to motor-module
    [heater.kicad_pcb, heater.sch, motor.kicad_pcb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]
2019-01-07 Heater major work done; left to design border cuts
    [heater.sch]
2019-01-08 heater done
    [boardOutline.fcstd, heater.kicad_pcb, heater.sch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]
2019-01-09 added indicator LED's in heater module; added proper markings in motor module.
    [boardOutline.fcstd, heater.kicad_pcb, heater.sch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]
2019-01-10 labelled trafficLight module
    [motor.kicad_pcb, traffic.kicad_pcb]
2019-01-14 mounting holes in motor, extra pins in traffic, corrections in labels
    [heater.kicad_pcb, motor.kicad_pcb, motor.sch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]
2019-01-14 labels in trafficc
    [traffic.kicad_pcb]
2019-01-14 designed and added proper cutlines for switches
    [boardoutlineSwithes.fcstd, cutlineSwitch.dxf, switches.kicad_pcb]
2019-01-16 changed switch PCB size to 9x5 cm
    [boardoutlineSwithes.fcstd, cutlineSwitch.dxf, switches.kicad_pcb]
2019-01-16 added a bit more description in README
    [boardoutlineSwithes.fcstd]
2019-01-17 corrected the mounting-scre-hole sizes to 3mm dia. drew symmetrical cutline for motor. updated README with new board images.
    [boardoutlineSwithes.fcstd, motor.kicad_pcb, motorCutlines.dxf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]
2019-01-21 created .csv bom file & also created interactive-html-bom for eac module
    [motor.kicad_pcb, motor.xml, switches.kicad_pcb]
2019-01-22 Consolidated BOM added
    [bomConsolidated.ods, motor.xml]
2019-01-22 gerbers generate
    [heater-B.Cu.gbr, heater-B.Mask.gbr, heater-B.Paste.gbr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]
2019-01-22 transistor driving in traffic light; updated the BOM and gerbers accordingly
    [bomConsolidated.ods, switches.kicad_pcb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]
2019-01-24 majorly - added port numbers; rotated 7805
    [bomConsolidated.ods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]
2019-02-26 swapped power and switch connector postions
    [heater.sch, motor.kicad_pcb]
2019-03-04 altered switches-board design; shifted resistor
    [switches.kicad_pcb, switches.sch]
2019-03-20 label correction&additions in traffic&switches modules. Updated gerbers - both V1 and modules
    [heater-B.Cu.gbr, heater-B.Mask.gbr, heater-B.Paste.gbr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]
